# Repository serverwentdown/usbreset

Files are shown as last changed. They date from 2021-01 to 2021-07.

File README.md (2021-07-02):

# usbreset

A little dongle-like thing to hard reset USB devices

## KiCad 3D View

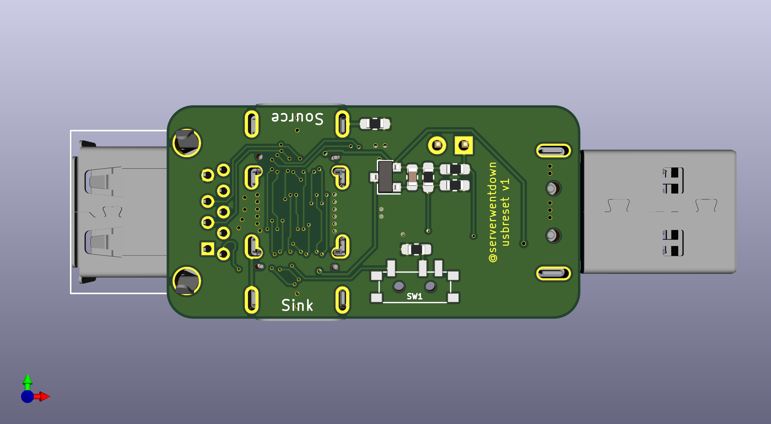
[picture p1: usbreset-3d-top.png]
3D view of the top

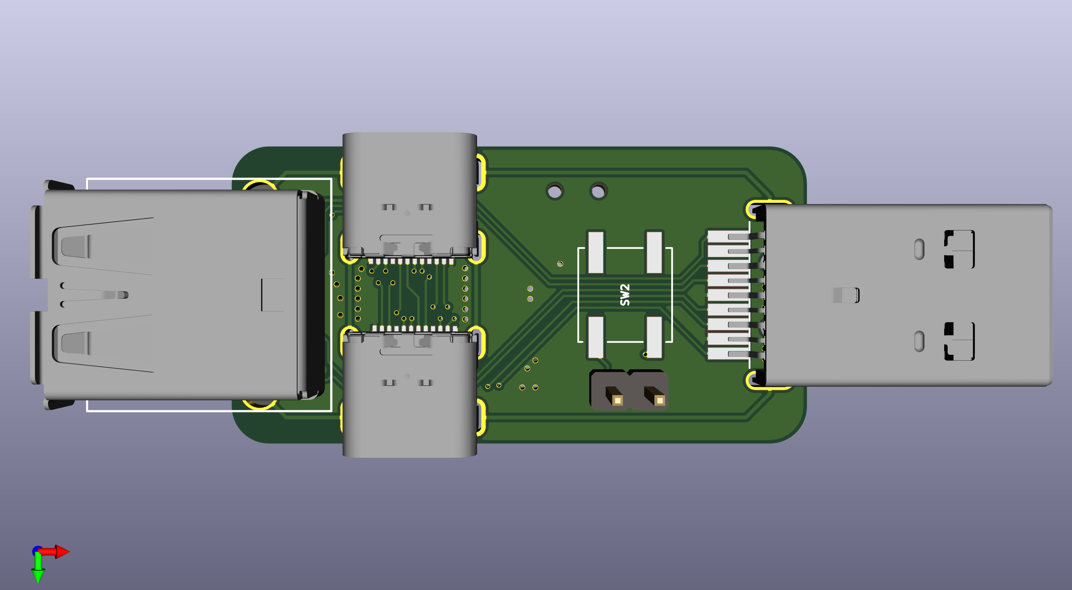
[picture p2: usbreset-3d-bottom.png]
3D view of the bottom


## Partially Populated Board

(Note the swapped USB D+/D- wires, those were fixed)

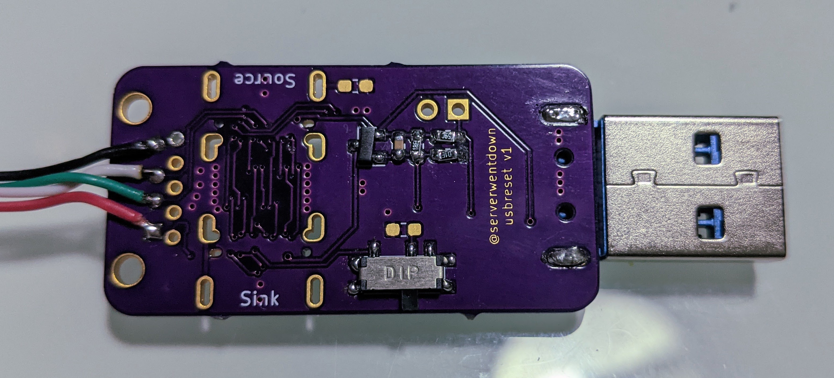
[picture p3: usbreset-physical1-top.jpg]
Physical partially-soldered board


<!-- vim: set conceallevel=2 et ts=2 sw=2: -->

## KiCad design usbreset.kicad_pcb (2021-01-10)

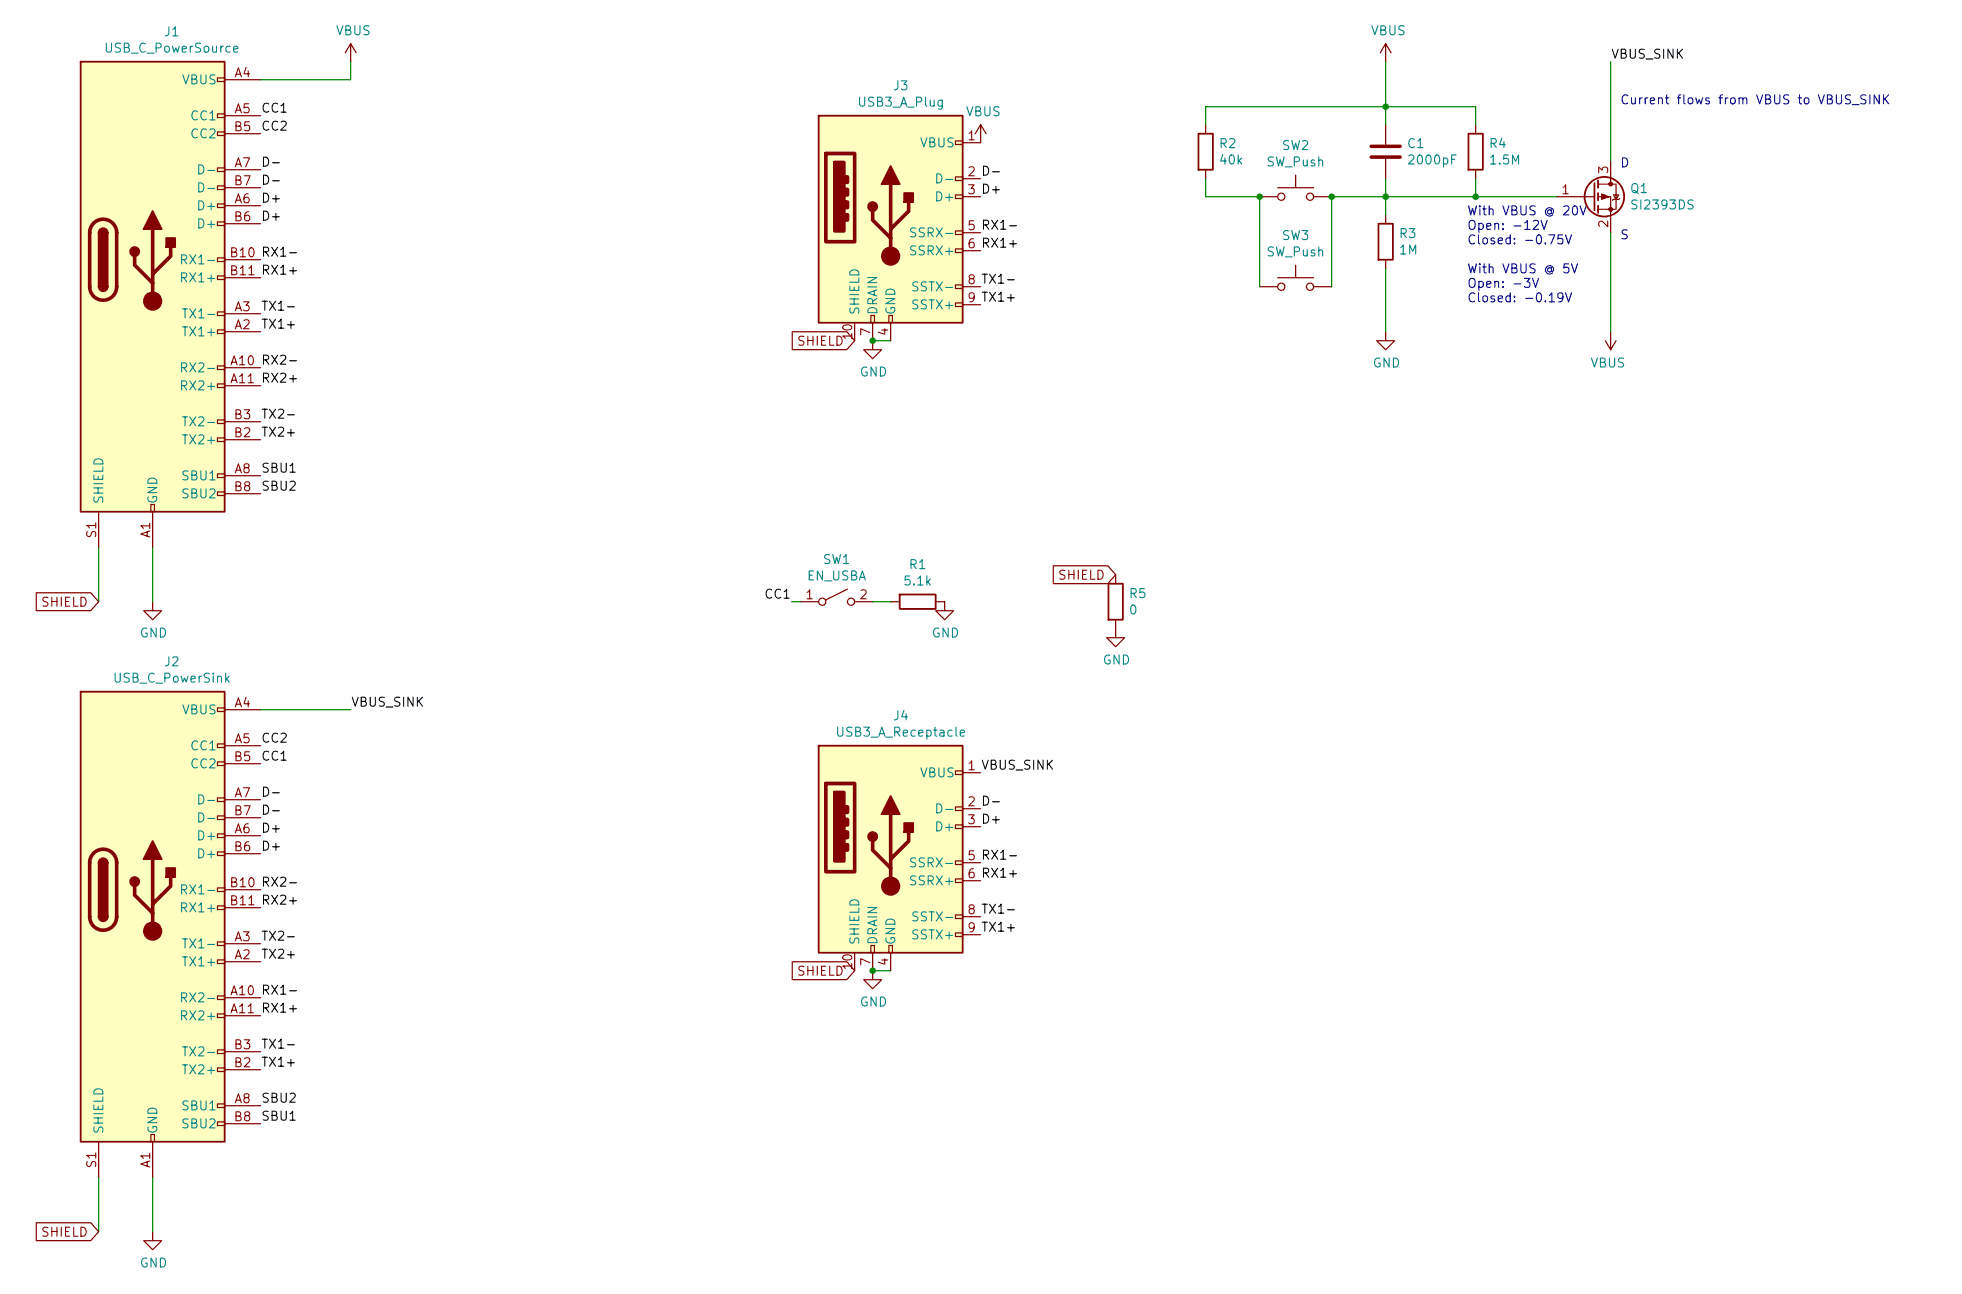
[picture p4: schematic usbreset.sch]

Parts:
C1: 2000pF; C_0603_1608Metric
J1: USB_C_PowerSource; USB_C_Receptacle_Amphenol_10137065
J2: USB_C_PowerSink; USB_C_Receptacle_Amphenol_10137065
J3: USB3_A_Plug; USB_A_Plug_Amphenol_GSB3164x1CEU
J4: USB3_A_Receptacle; USB_A_Receptacle_Amphenol_10117835
Q1: SI2393DS; SOT-23
R1: 5.1k; R_0603_1608Metric_Pad1.05x0.95mm_HandSolder
R2: 40k; R_0603_1608Metric_Pad1.05x0.95mm_HandSolder
R3: 1M; R_0603_1608Metric_Pad1.05x0.95mm_HandSolder
R4: 1.5M; R_0603_1608Metric_Pad1.05x0.95mm_HandSolder
R5: 0; R_0603_1608Metric_Pad1.05x0.95mm_HandSolder
SW1: EN_USBA; SW_SPDT_MSS3-V-T_R
SW2: SW_Push; SW_Push_1P1T_NO_CK_KSC7xxJ
SW3: SW_Push; PinHeader_1x02_P2.54mm_Vertical

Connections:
/CC1: J1.A5 (CC1), J2.B5 (CC2), SW1.1 (A)
/CC2: J1.B5 (CC2), J2.A5 (CC1)
/D+: J1.A6 (D+), J1.B6 (D+), J2.A6 (D+), J2.B6 (D+), J3.3 (D+), J4.3 (D+)
/D-: J1.A7 (D-), J1.B7 (D-), J2.A7 (D-), J2.B7 (D-), J3.2 (D-), J4.2 (D-)
/RX1+: J1.B11 (RX1+), J2.A11 (RX2+), J3.6 (SSRX+), J4.6 (SSRX+)
/RX1-: J1.B10 (RX1-), J2.A10 (RX2-), J3.5 (SSRX-), J4.5 (SSRX-)
/RX2+: J1.A11 (RX2+), J2.B11 (RX1+)
/RX2-: J1.A10 (RX2-), J2.B10 (RX1-)
/SBU1: J1.A8 (SBU1), J2.B8 (SBU2)
/SBU2: J1.B8 (SBU2), J2.A8 (SBU1)
/TX1+: J1.A2 (TX1+), J2.B2 (TX2+), J3.9 (SSTX+), J4.9 (SSTX+)
/TX1-: J1.A3 (TX1-), J2.B3 (TX2-), J3.8 (SSTX-), J4.8 (SSTX-)
/TX2+: J1.B2 (TX2+), J2.A2 (TX1+)
/TX2-: J1.B3 (TX2-), J2.A3 (TX1-)
/VBUS_SINK: J2.A4 (VBUS), J2.A9 (VBUS), J2.B4 (VBUS), J2.B9 (VBUS), J4.1 (VBUS), Q1.3 (D)
GND: J1.A1 (GND), J1.A12 (GND), J1.B1 (GND), J1.B12 (GND), J2.A1 (GND), J2.A12 (GND), J2.B1 (GND), J2.B12 (GND), J3.4 (GND), J3.7 (DRAIN), J4.4 (GND), J4.7 (DRAIN), R1.1, R3.2, R5.2
unnamed: C1.2, Q1.1 (G), R3.1, R4.2, SW2.2, SW3.2
unnamed: R1.2, SW1.2 (B)
unnamed: R2.2, SW2.1, SW3.1
SHIELD: J1.S1 (SHIELD), J2.S1 (SHIELD), J3.10 (SHIELD), J4.10 (SHIELD), R5.1
VBUS: C1.1, J1.A4 (VBUS), J1.A9 (VBUS), J1.B4 (VBUS), J1.B9 (VBUS), J3.1 (VBUS), Q1.2 (S), R2.1, R4.1

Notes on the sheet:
Current flows from VBUS to VBUS_SINK
With VBUS @ 20V Open: -12V Closed: -0.75V With VBUS @ 5V Open: -3V Closed: -0.19V

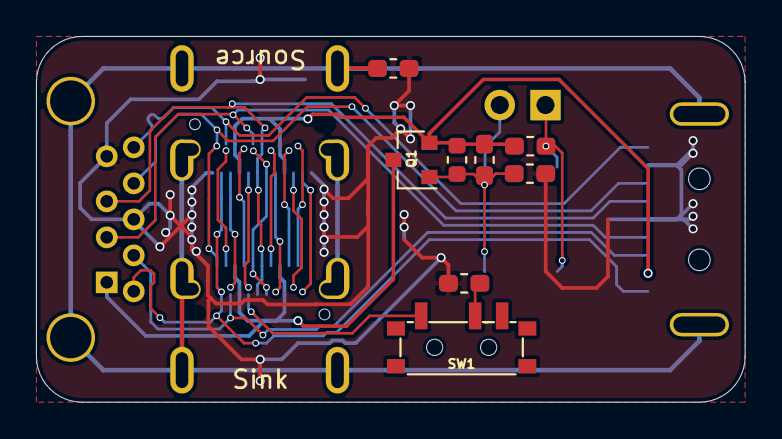
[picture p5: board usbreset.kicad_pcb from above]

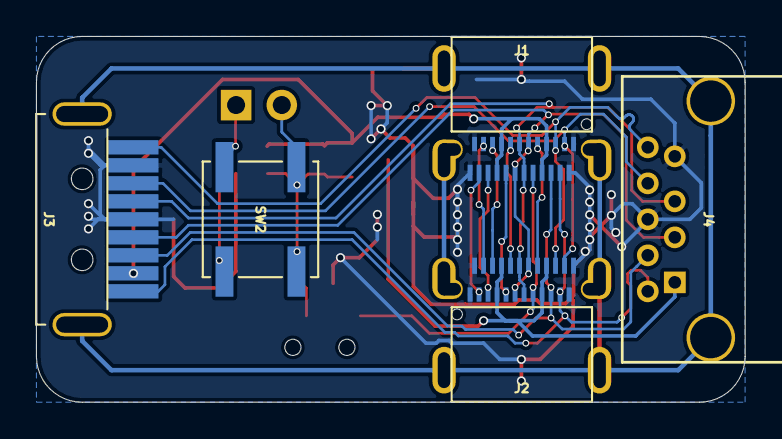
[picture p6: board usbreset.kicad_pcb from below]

Board: 2 copper layers, 39.4 x 20.3 mm, 14 parts (6 on the bottom side), 21 nets.

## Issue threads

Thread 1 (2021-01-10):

PCB could be slimmer

serverwentdown, 2021-01-10:
Currently, there is quite a large gap between both USB C connectors. This can be removed to reduce the width of the entire board.

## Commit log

2020-12-13 Initial custom footprints
    [usbreset.kicad_pcb, usbreset.sch]
2020-12-13 Use library in schematic
    [usbreset.sch]
2020-12-13 Initial PCB layout
    [usbreset.kicad_pcb, usbreset.sch]
2020-12-13 More tweaks
    [usbreset.kicad_pcb]
2020-12-19 Route most connections
    [usbreset.kicad_pcb, usbreset.sch]
2020-12-19 Finish 1st routing pass, add 3D preview
    [usbreset.kicad_pcb]
2021-01-10 Improve GND routing
    [usbreset.kicad_pcb, usbreset.sch]
2021-07-02 Add physical soldered prototype
